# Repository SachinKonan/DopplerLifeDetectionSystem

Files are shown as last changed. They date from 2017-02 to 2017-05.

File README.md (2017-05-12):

# Doppler Radar Based Life Detection System

This project aimed at designing a low-cost Doppler radar system capable of detectin earthquake victims buried under rubble. The original system started with a cheap HB-100 system (located in ScienceFair2016), but after a summer's worth of research a from-scratch system was redesigned, requiring electrical and software innovation. The radar features a front-end clutter cancellation system which enables it to ignore the strong frontal reflections, allowing it to have hypersensitivity to signals through the rubble. Current work lies with redesigning the system on a printed circuit board for mobile deployment. 
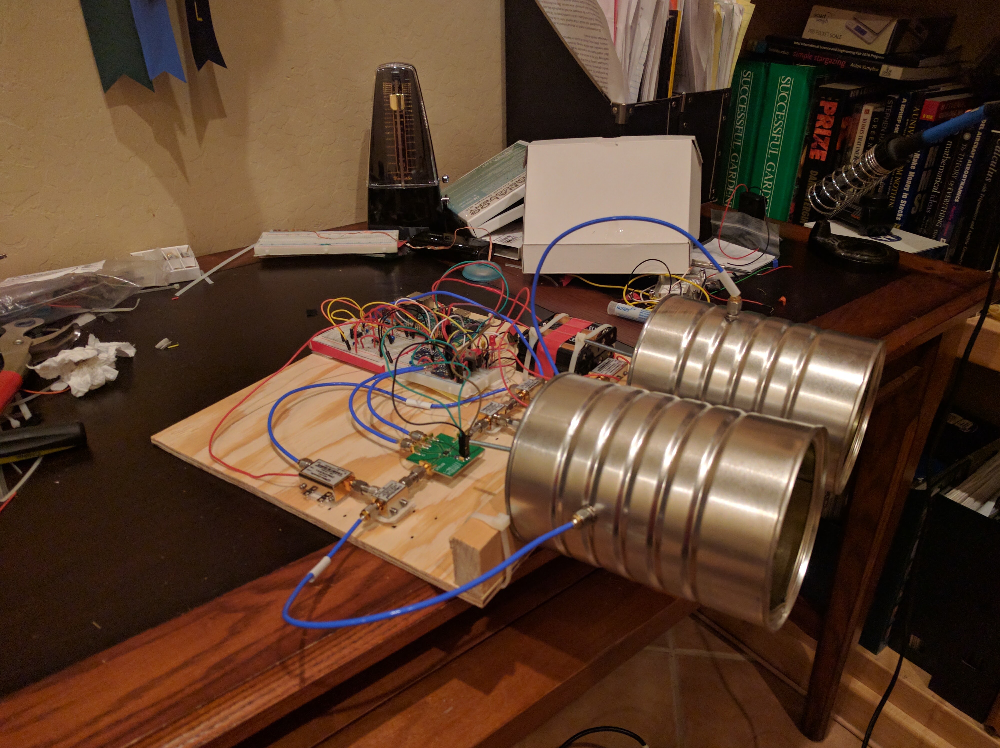
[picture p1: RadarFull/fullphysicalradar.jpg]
Doppler


## Research Paper
The full, Latex Paper can be found under the Research tab. 

## Hardware Build

The Schematic for the entire radar is found under the RadarFull tab. This includes the connections of the RF components, the filter/amplifier circuit, power supply, and list of materials.

### PCB

A PCB radar was designed on Upverter and the gerber files can be found in the PCBRadar folder. 

## Software

### Simple Oscillscope

Under main/SimpleOscilloscope a oscilloscope was designed as an intermediate step in the project, but may be a useful tool for anyone looking to debug circuits. The oscilloscope has a simple gui interface and the hookups of the connections can be found on the start page of the gui. 

### DAC And ADC Support

In order to speed up ADC and DAC control, threaded classes for the ADS-1115 and MCP-4725 were constructed -- main/ADC and main/DAC. These classes require the bare-bone libraries provided by adafruit: 

https://github.com/adafruit/Adafruit_Python_ADS1x15

https://github.com/adafruit/Adafruit_Python_MCP4725

These classes will run idly while simple getters and setters can be used to manipulate inputs/outputs. Additionally within the DAC folder sample classes for sin-wave, triangle-wave, square wave, and user set wave are provided. 

### Signal Processing

A FIR Filter and a Custom Signal Processing algorithm can be found in main/DSP. The Signal Processing algorithm is described in the paper. 

### Clutter Cancellatiion 

Found under main/Clutter-Cancellation. Currently in rats-nest state as the majority of testing occured in this folder. The results of the testing in the filter are found in the realmain.py file in main

### Radar Simulations

To demonstrate that DC offset corresponds to the amount of clutter in the radar system, a python simulation was constructed which can be found in main/Simulations. Once run
### Final

Once all pin connections are made correct according to the picture in main/radarfull.png, main/realmain.py can be run, which has three tabs.

1) Clutter Cancellation - Will run cancellation algorithm and minimize clutter in the receive antenna (approach described in paper). 
2) Data Collection and Processing - Will collect 2500 samples and output an FFT of the processed data. 
3) Simple Oscilloscope - Can be used for debugging within the system. 

# Author
Sachin Konan - Have been working on this work for 1.5 years +
James Aberle - Mentor for the project, aiding in rf clutter cancellation design.

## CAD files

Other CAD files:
CADFIles/Antenna.ipt
CADFIles/OldVersions/Antenna.0002.ipt
CADFIles/case.ipt
CADFIles/fullcase.iam

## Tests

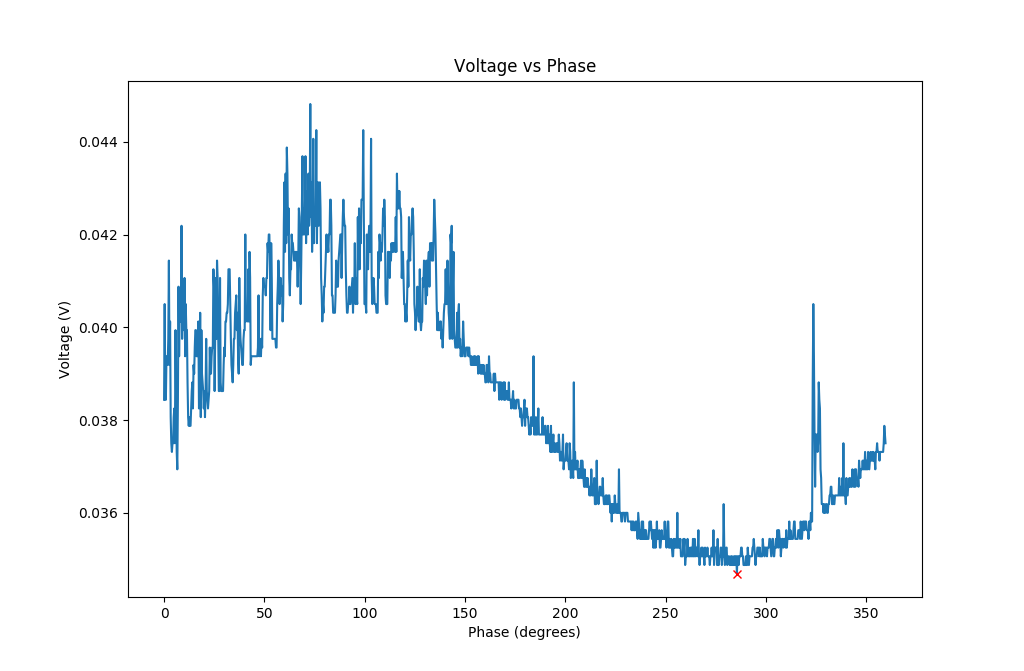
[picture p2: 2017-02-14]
main/CancellationCode/CalibrationGraphs/voltvsphase4.png

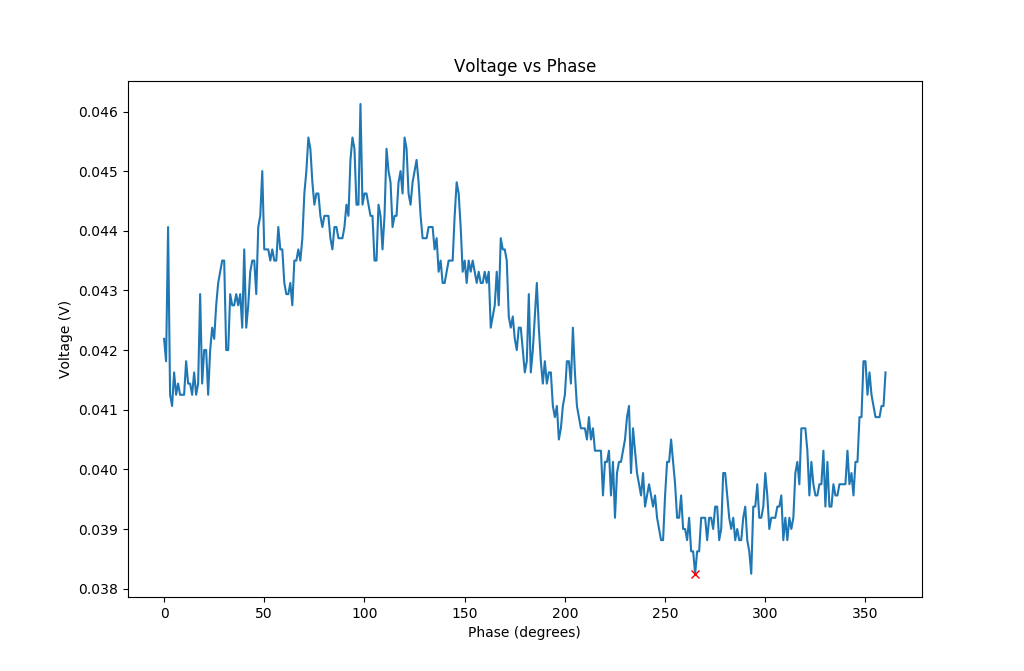
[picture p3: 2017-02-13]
main/CancellationCode/CalibrationGraphs/voltvsphase.png

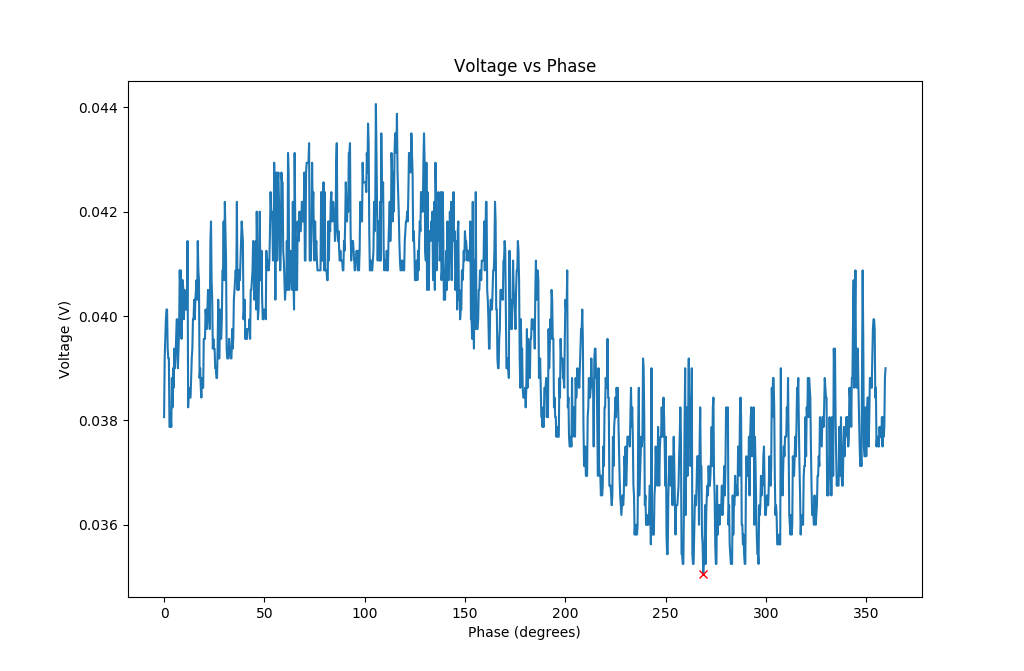
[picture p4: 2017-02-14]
main/CancellationCode/CalibrationGraphs/voltvsphase6.png

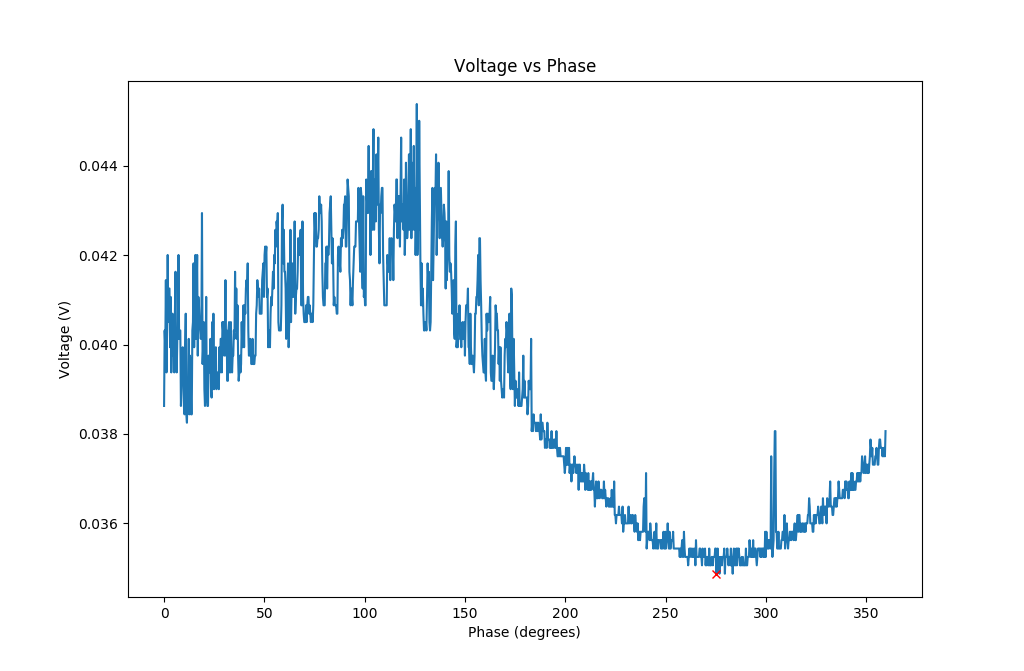
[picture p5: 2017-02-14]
main/CancellationCode/CalibrationGraphs/voltvsphase5.png

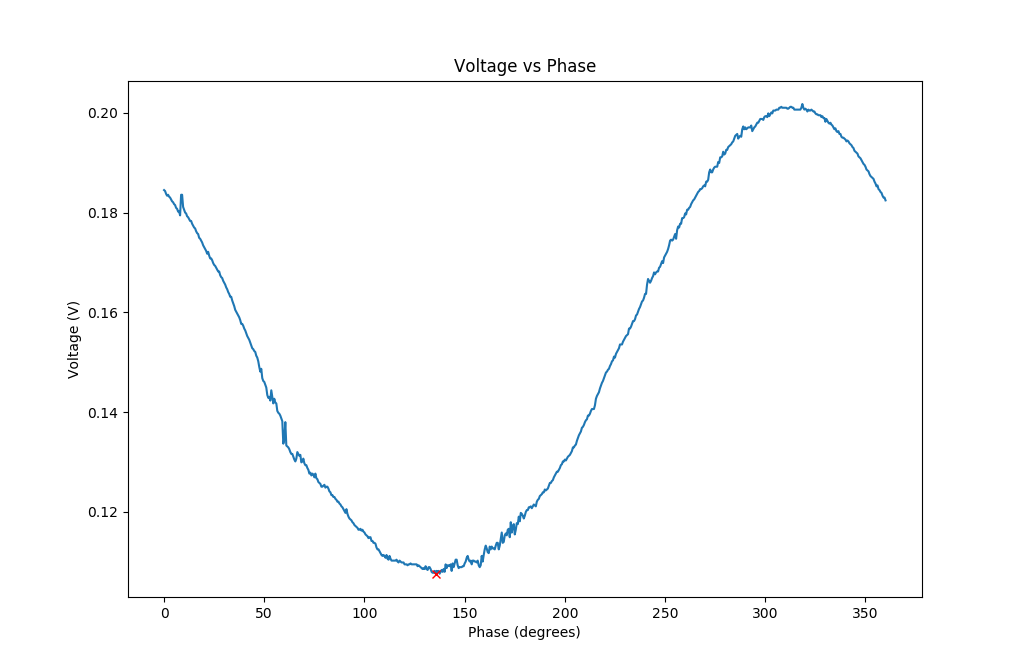
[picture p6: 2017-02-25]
main/CancellationCode/CalibrationGraphs/voltvsphasevalidation2.png

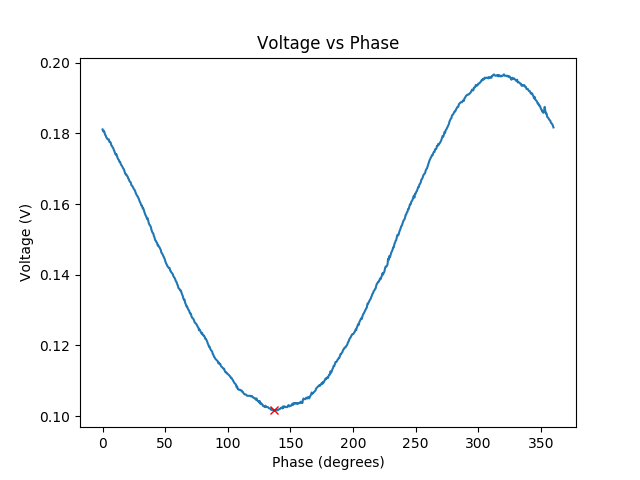
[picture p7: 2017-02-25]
main/CancellationCode/CalibrationGraphs/voltvsphasevalidatedwamp.png

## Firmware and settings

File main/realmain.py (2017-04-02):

import tkinter as tk
from tkinter import ttk
import matplotlib
import matplotlib.pylab as plt
from matplotlib.backends.backend_tkagg import FigureCanvasTkAgg, NavigationToolbar2TkAgg
from matplotlib.figure import Figure
from matplotlib import style
import time
from threading import Thread
import tkinter.simpledialog as simpledialog
import os
import numpy as np
import matplotlib.pyplot as plt
from scipy.fftpack import fft
from scipy.linalg import hankel
from scipy.signal import butter, lfilter, freqz
import Adafruit_ADS1x15
import Adafruit_MCP4725


def convertValtoVolt(x):
    return int((x / 3.3) * 4096.0)

class ADCThread:
    def __init__(self, address=0x48, gain=2 / 3, numthreads=1):
        self.i2caddress = address
        self.adc = Adafruit_ADS1x15.ADS1115(self.i2caddress)
        self.GAIN = gain
        self.numthreads = numthreads
        self.interrupt = False
        self.stopA1 = False
        self.stopA2 = False
        self.stopA3 = False
        self.adcval1 = 0
        self.adcval2 = 0
        self.adcval3 = 0
        self.adcval4 = 0
        self.samples = 0
        self.start_time = 0
        self.end_time = 0
        self.samplingrate = 0

    def start(self):
        Thread(target=self.channel, args=()).start()
        return self

        # self.start_time = time.time()
        # Thread(target = self.channel2,args = ()).start()

    def channel(self):
        i = 0
        i1 = 1
        while True:
            if (self.interrupt):
                return
            else:
                self.adcval1 = (self.adc.read_adc(0, gain=self.GAIN) / 32767.0) * 6.144
                self.adcval2 = (self.adc.read_adc(1, gain=self.GAIN) / 32767.0) * 6.144
                self.adcval3 = (self.adc.read_adc(2, gain=self.GAIN) / 32767.0) * 6.144
                self.adcval4 = (self.adc.read_adc(3, gain=self.GAIN) / 32767.0) * 6.144
                # self.end_time = time.time()
                # self.samples+=1
                time.sleep(0.01)

    def getADCVAL(self, var):
        if (var == 0):
            return self.adcval1
        elif (var == 1):
            return self.adcval2
        elif (var == 2):
            return self.adcval3
        elif (var == 3):
            return self.adcval4
        else:
            pass
    def stop(self):
        self.interrupt = True


class dacThreadVAL:
    def __init__(self, address):
        self.i2caddress = address
        self.interrupt = False
        self.dac = Adafruit_MCP4725.MCP4725(self.i2caddress)
        self.val = 0

    def start(self):
        print('Starting DAC Thread')
        Thread(target=self.valueset, args=()).start()
        return self

    def valueset(self):
        while True:
            if (self.interrupt):
                return
            else:
                if (self.val >= 0 and self.val <= 4096):
                    self.dac.set_voltage(self.val, True)

    def updateVal(self, val):
        self.val = val

    def stop(self):
        self.interrupt = True


style.use("ggplot")
matplotlib.use("TkAgg")
large_font = ("Verdana", 12)
small_font = ("Verdana", 8)

phasedac = dacThreadVAL(0x63).start()
ampdac = dacThreadVAL(0x62).start()
adc = ADCThread().start()
isOn = True
class MainGui(tk.Tk):
    def __init__(self, *args, **kwargs):
        tk.Tk.__init__(self, *args, **kwargs)
        container = tk.Frame(self)

        container.pack(side="top", fill="both", expand=True)
        container.grid_rowconfigure(0, weight=1)
        container.grid_columnconfigure(0, weight=1)
        self.frames = {}

        for F in (StartPage, PageOne, PageTwo, PageThree):
            frame = F(container, self)
            self.frames[F] = frame
            frame.grid(row=0, column=0, sticky="nsew")
        self.show_frame(StartPage)

    def show_frame(self, cont):
        frame = self.frames[cont]
        frame.tkraise()


class StartPage(tk.Frame):
    def __init__(self, parent, controller):
        tk.Frame.__init__(self, parent)
        label = tk.Label(self, text="Start Page", font=large_font)
        label.pack(pady=10, padx=10)
        button1 = ttk.Button(self, text="Calibration", command=lambda: controller.show_frame(PageOne))
        button1.pack()
        button2 = ttk.Button(self, text="Visit Data Acquisition", command=lambda: controller.show_frame(PageTwo))
        button2.pack()
        button3 = ttk.Button(self, text="Visit Oscilloscope", command=lambda: controller.show_frame(PageThree))
        button3.pack()


class PageOne(tk.Frame):
    def __init__(self, parent, controller):
        tk.Frame.__init__(self, parent)
        label = tk.Label(self, text="Calibration", font=large_font)
        label.pack(pady=10, padx=10)

        self.statuslabel = tk.Label(self, text="Not Calibrating", font=small_font, fg='red')
        self.statuslabel.pack(side=tk.BOTTOM)

        button = ttk.Button(self, text="Back to Home", command=lambda: controller.show_frame(StartPage))
        button.pack()

        button3 = ttk.Button(self, text="Calibration", command=self.calibrate)
        button3.pack()

        f = Figure(figsize=(6, 4), dpi=100)

        self.ax = f.add_subplot(2, 1, 1)
        self.ax2 = f.add_subplot(2, 1, 2)
        self.ax.text(.5, .9, 'Voltage vs Phase', horizontalalignment='center', transform=self.ax.transAxes, size=13,
                     color='r')
        self.ax2.text(.5, .9, 'Voltage vs Amp', horizontalalignment='center', transform=self.ax2.transAxes, size=13,
                      color='r')
        self.ax.grid(True)
        self.ax2.grid(True)

        self.canvas = FigureCanvasTkAgg(f, master=self)
        self.canvas.show()
        self.canvas.get_tk_widget().pack(side=tk.BOTTOM, fill=tk.BOTH, expand=True)

    def calibrate(self):
        gain = -10
        MAX_GAIN = -10
        keyvals = [10, 10]
        xvals = []
        yvals = []
        time.sleep(1)
        x = 0
        self.statuslabel['text'] = "Starting Phase"
        while (x <= 360):
            a = gain / 20
            b = MAX_GAIN / 20
            G = 10 ** a
            Gmax = 10 ** b
            vi = 1.5 + 1.0 * (G / Gmax) * np.cos(x * np.pi / 180)
            vq = 1.5 + 1.0 * (G / Gmax) * np.sin(x * np.pi / 180)
            phasedac.updateVal(convertValtoVolt(vi))
            ampdac.updateVal(convertValtoVolt(vq))
            time.sleep(0.08)
            val = adc.getADCVAL(0)
            # val = np.random.rand() * 2 - 1
            if (abs(val) < abs(keyvals[1])):
                keyvals[0] = x
                keyvals[1] = val
            xvals.append(x)
            yvals.append(val)
            x += 0.5
        # print('Min Phase: %s' % (keyvals[0]))
        # print('Min Voltage: %s' %(keyvals[1]))
        self.statuslabel['text'] = "Finished Phase, Starting AMP"
        self.ax.plot(xvals, yvals)
        self.ax.plot(keyvals[0], keyvals[1], marker='x', color='r')
        self.canvas.show()
        phase = keyvals[0]
        keygainvals = [[0, 0, 0], 10]

        xvals2 = []
        yvals2 = []
        while gain >= -40:
            a = gain / 20
            b = MAX_GAIN / 20
            G = 10 ** a
            Gmax = 10 ** b
            vi = 1.5 + 1.0 * (G / Gmax) * np.cos(phase * np.pi / 180)
            vq = 1.5 + 1.0 * (G / Gmax) * np.sin(phase * np.pi / 180)
            biti = convertValtoVolt(vi)
            bitq = convertValtoVolt(vq)
            phasedac.updateVal(biti)
            ampdac.updateVal(bitq)
            time.sleep(0.1)
            val = adc.getADCVAL(0)
            if (abs(val) < abs(keygainvals[1])):
                keygainvals[0][0] = biti
                keygainvals[0][1] = bitq
                keygainvals[0][2] = gain
                keygainvals[1] = val
            xvals2.append(gain)
            yvals2.append(val)

            gain -= 0.2
        self.statuslabel['text'] = "Finished AMP"
        self.ax2.plot(xvals2, yvals2)
        self.ax2.plot(keygainvals[0][2], keygainvals[1], marker='x', color='r')

        biti = keygainvals[0][0]
        bitq = keygainvals[0][1]

        phasedac.updateVal(biti)
        ampdac.updateVal(bitq)
        self.canvas.show()

class PageTwo(tk.Frame):
    def __init__(self, parent, controller):
        tk.Frame.__init__(self, parent)
        label = tk.Label(self, text="Data Acquisition", font=large_font)
        label.pack(pady=10, padx=10)

        button1 = ttk.Button(self, text="Back to Home", command=lambda: controller.show_frame(StartPage))
        button1.pack()

        self.statuslabel = tk.Label(self, text="Status", font=large_font)
        self.statuslabel.pack(pady=30, padx=30)

        button3 = ttk.Button(self, text="Data Acqusition Button for 2500 Samp", command=self.showBox)
        button3.pack()

        f = Figure(figsize=(6, 4), dpi=100)

        self.ax = f.add_subplot(1, 1, 1)
        self.ax.set_title("FFT of Selected Data")
        self.ax.set_xlabel("Frequency")
        self.ax.set_ylabel("Power (dB)")
        self.ax.grid(True)
        self.canvas = FigureCanvasTkAgg(f, master=self)
        self.canvas.show()
        self.canvas.get_tk_widget().pack(side=tk.BOTTOM, fill=tk.BOTH, expand=True)

    def showBox(self):
        string = simpledialog.askstring("Hello", "Prompt")

        if (string != None):
            self.statuslabel['text'] = "Starting Data Acquisistion"
            data, Fs = self.arraySampler()

            self.statuslabel['text'] = "Saving to: " + string
            path = 'C:\\Users\\Sachin Konan\\Documents\\ScienceFair2017\\main\\gui\\datasets'
            np.save(os.path.join(path, string), data)
            self.statuslabel['text'] = "Finished Saving"

            analysis = Radar(radar=data, samplingRate=Fs)
            output = analysis.main()
            mess = ''
            if (output['loc'] > 0.05 and output['loc'] < 3.3):
                mess = 'Possible Person'
            else:
                mess = 'None'
            self.ax.plot(output['fft'][0], output['fft'][1])
            self.ax.plot(output['loc'], output['peak'], marker='x', color='r')
            self.ax.text(output['fft'][0][len(output['fft'][0]) - 1] - 3, output['peak'] - 1, mess)
            self.canvas.show()

        else:
            pass

    def arraySampler(self):
        data = []
        start = time.time()
        for i in range(0, 2500):
            # data.append(adc.getADCVAL(0))
            data.append([np.random.rand() * 2 - 1, time.time()])
        end = time.time()
        Fs = (end - start) / 2500
        return data, Fs


class PageThree(tk.Frame):
    def __init__(self, parent, controller):
        tk.Frame.__init__(self, parent)

        self.controller = controller
        label = tk.Label(self, text="Oscilloscope", font=large_font)
        label.pack(pady=10, padx=10)

        button1 = ttk.Button(self, text="Back to Home", command=lambda: self.pageChanger())
        button1.pack()

        self.channel = 0
        self.label5 = tk.Label(self, text="Current Channel: " + str(self.channel), font=small_font)
        self.label5.pack(side=tk.BOTTOM)

        self.phase = tk.Scale(self, label="DAC1 :", from_=0, to=4096, sliderlength=20, length=400, orient=tk.HORIZONTAL)
        self.amplitude = tk.Scale(self, label="DAC2 :", from_=0, to=4096, sliderlength=20, length=400,orient=tk.HORIZONTAL)
        self.phase.pack(side=tk.TOP, padx=2, pady=5)
        self.amplitude.pack(side=tk.TOP, padx=2, pady=5)

        frame = tk.Frame(self)
        frame.pack(side=tk.RIGHT, fill=tk.BOTH)

        chan1 = ttk.Button(frame, text="Channel 0", command=lambda: self.add(0))
        chan1.pack(pady=35, padx=20)
        chan2 = ttk.Button(frame, text="Channel 1", command=lambda: self.add(1))
        chan2.pack(pady=35, padx=20)
        chan3 = ttk.Button(frame, text="Channel 2", command=lambda: self.add(2))
        chan3.pack(pady=35, padx=20)
        chan4 = ttk.Button(frame, text="Channel 3", command=lambda: self.add(3))
        chan4.pack(pady=35, padx=20)

        f = Figure(figsize=(5, 4), dpi=100)
        self.ax = f.add_subplot(111)
        self.ax.grid(True)

        xAchse = plt.arange(0, 100, 1)
        yAchse = plt.array([0] * 100)

        self.ax.grid(True)
        self.ax.set_title("Realtime Waveform Plot")
        self.ax.set_xlabel("Time")
        self.ax.set_ylabel("Amplitude")
        self.ax.axis([0, 100, -5, 5])
        self.line1 = self.ax.plot(xAchse, yAchse, '-')

        self.canvas = FigureCanvasTkAgg(f, master=self)
        self.canvas.get_tk_widget().pack(side=tk.LEFT, fill=tk.BOTH, expand=True)

        self.values = [0 for x in range(100)]

        # self.after(ms=100, func=self.SinwaveformGenerator)
        # self.after(ms=100, func=self.RealtimePlotter)

        self.thread = Thread(target=self.SinwaveformGenerator, args=())
        self.thread.start()

        self.thread1 = Thread(target=self.RealtimePlotter, args=())
        self.thread1.start()

    def pageChanger(self):
        self.controller.show_frame(StartPage)
        self.thread.join()
        self.thread1.join()

    def add(self, var):
        self.channel = var
        self.label5["text"] = "Current Channel is " + str(self.channel)

    def controlDACPhase(self):
        # print(self.phase.get())

        valstring = str(self.phase.get())

        try:
            val = int(valstring)
            # print(val)
            phasedac.updateVal(val)
        except ValueError:
            print("cant convert")
        self.update()

    def controlDACAmp(self):

        valstring = str(self.amplitude.get())

        try:
            val = int(valstring)
            # print(val)
            ampdac.updateVal(val)
        except ValueError:
            print("can't convert")
        self.update()

    def SinwaveformGenerator(self):

        # add adc stuff here
        # self.values.append(adc.getADCVAL(self.channel))
        self.controlDACPhase()
        self.controlDACAmp()
        # self.values.append(np.random.rand()*2 -1)
        self.values.append(adc.getADCVAL(self.channel))
        self.after(ms=25, func=self.SinwaveformGenerator)
        # time.sleep(0.025)
        # self.SinwaveformGenerator()

    def RealtimePlotter(self):
        CurrentXAxis = plt.arange(len(self.values) - 100, len(self.values), 1)
        self.line1[0].set_data(CurrentXAxis, plt.array(self.values[-100:]))
        self.ax.axis([CurrentXAxis.min(), CurrentXAxis.max(), 0, 5])
        self.canvas.draw()
        self.after(ms=25, func=self.RealtimePlotter)

    def converttoVolt(x):
        return (x / 4096) * 3.3


class Radar(object):
    def __init__(self, radar, samplingRate):
        self.radar = [radar[i][0] for i in range(0, len(radar))]
        self.time = [radar[i][1] for i in range(0, len(radar))]
        self.samplingRate = samplingRate
        self.p = 5
        self.nfft = 512
        self.list = []
        self.cutoff = 2
        self.radarobj = None
        self.order = 6

    def getVariables(self):
        return self.samplingRate, self.radar, self.time

    def main(self):
        radar, time = self.slidingwindow()
        fft = self.fft(radar)
        peakY = np.max(fft[1])  # Find max peak
        locY = fft[0][np.argmax(fft[1])]  # Find its location
        return {
            'fft': fft,
            'peak': peakY,
            'loc': locY
        }

    def slidingwindow(self):

        if (len(self.radar) == 2500):
            overlap = 0.4

            nw = 250
            ns = int(nw * (1.0 - overlap))
            n0 = 0
            n1 = n0 + nw
            N = len(self.radar)

            counter = 0
            counter1 = 1

            SNR = 0
            bestwin = 0
            besttime = 0
            while True:
                data = self.radar[n0:n1]
                time = self.time[n0:n1]
                array = Radar.HanningFunction(data)
                filtered_data = Radar.butter_lowpass_filter(array, self.cutoff, self.samplingRate, order=self.order)
                corrMtrx = self.getcorrMtrx(x=filtered_data, m=35)
                frequency, psd, eigenvals = self.musicAlg(corrMtrx)
                currSNR = sum(eigenvals[0:self.p]) / sum(eigenvals[self.p: len(eigenvals)])
                if (currSNR > SNR):
                    SNR = currSNR
                    bestwin = filtered_data
                    besttime = time
                # r = counter // n
                # c = counter % n
                # ax[r][c].plot(eigenvals)
                # ax[r][c + 1].plot(xf, yf)
                n0 += ns
                n1 += ns
                counter += 2
                counter1 += 1
                if n1 > N:
                    break

            return bestwin, besttime
        else:
            print("Error your data vector is not the proper length")

    def diffCalc(self, list1):
        list2 = []
        for i in range(1, len(list1)):
            list2.append(list1[i] - list1[i - 1])
        return list2

    def fft(self, array):
        yf = fft(array, n=self.nfft)
        xf = np.linspace(0.0, self.samplingRate / 2, self.nfft / 2)
        return xf, abs(yf[0:self.nfft / 2])

    def HanningFunction(radarData):
        return radarData * np.hanning(len(radarData))

    def getcorrMtrx(self, x, m):
        x = np.array(x)
        m = m
        N = len(x)
        xlen = m + 1
        rowVector = x[N - xlen: N]
        columnVector = x[0: N - m]
        hanMatrix = hankel(c=np.array(columnVector).T, r=rowVector)
        X_unscaled = np.fliplr(hanMatrix)
        X = X_unscaled / np.sqrt(N - m)
        Xnew = np.conj(np.fliplr(X))
        corrMatrix = np.vstack((X, Xnew)) / np.sqrt(2)
        return corrMatrix

    def musicAlg(self, corrMtrx):
        u, s, v = np.linalg.svd(corrMtrx)

        self.nfft = 512

        frequencyVector = np.linspace(0, 1, self.nfft // 2)
        frequencyVector *= self.samplingRate / 2

        sum = 0
        for i in range(self.p, len(v)):
            y = fft(v[i], n=self.nfft)
            sum += abs(y) ** 2 / s[i]

        sum = 1 / sum

        sum = sum[0:self.nfft // 2]

        return frequencyVector, sum, s

    def graphFilterResults(self):
        order = 6
        cutoff = 2

        b, a = Radar.butter_lowpass(cutoff, self.samplingRate, order)

        w, h = freqz(b, a, worN=8000)
        plt.subplot(2, 1, 1)
        plt.plot(0.5 * self.samplingRate * w / np.pi, np.abs(h), 'b')
        plt.plot(cutoff, 0.5 * np.sqrt(2), 'ko')
        plt.axvline(cutoff, color='k')
        plt.xlim(0, 0.5 * self.samplingRate)
        plt.title("Lowpass Filter Frequency Response")
        plt.xlabel('Frequency [Hz]')
        plt.grid()

        y = Radar.butter_lowpass_filter(self.radar, cutoff, self.samplingRate, order)

        plt.subplot(2, 1, 2)
        plt.plot(self.time, self.radar, 'b-', label='data')
        plt.plot(self.time, y, 'g-', linewidth=2, label='filtered data')
        plt.xlabel('Time [sec]')
        plt.grid()
        plt.legend()

        plt.subplots_adjust(hspace=0.35)
        plt.show()
        return y

    def butter_lowpass(cutoff, fs, order=5):
        nyq = 0.5 * fs
        normal_cutoff = cutoff / nyq
        b, a = butter(order, normal_cutoff, btype='low', analog=False)
        return b, a

    def butter_lowpass_filter(data, cutoff, fs, order=5):
        b, a = Radar.butter_lowpass(cutoff, fs, order=order)
        y = lfilter(b, a, data)
        return y

    def testSpectrum(self, data):
        corrMtrx = self.getcorrMtrx(data, 30)
        return self.musicAlg2(corrMtrx)

    def musicAlg2(self, corrMtrx):
        u, s, v = np.linalg.svd(corrMtrx)
        self.nfft = 512
        frequencyVector = np.linspace(0, 1, self.nfft // 2)
        frequencyVector *= self.samplingRate / 2
        sum = 0
        for i in range(self.p, len(v)):
            y = fft(v[i], n=self.nfft)
            sum += abs(y) ** 2 / s[i]

        sum = 1 / sum

        sum = sum[0:self.nfft // 2]

        return frequencyVector, sum, s


def on_closing():
    if tk.messagebox.askokcancel("Quit", "Do you want to quit?"):
        app.destroy()
    else:
        isOn = True


app = MainGui()
app.protocol("WM_DELETE_WINDOW", on_closing)
app.mainloop()

phasedac.stop()
ampdac.stop()
adc.stop()

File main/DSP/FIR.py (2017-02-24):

import numpy as np
from scipy import signal
import matplotlib.pyplot as plt


def plot_response(fs, w, h, title):
    plt.figure()
    plt.plot(0.5*fs*w/np.pi, 20*np.log10(np.abs(h)))
    plt.ylim(-40, 5)
    plt.xlim(0, 0.5*fs)
    plt.grid(True)
    plt.xlabel('Frequency (Hz)')
    plt.ylabel('Gain (dB)')
    plt.title(title)


# Low-pass filter design parameters
fs = 22050.0       # Sample rate, Hz
cutoff = 8000.0    # Desired cutoff frequency, Hz
trans_width = 250  # Width of transition from pass band to stop band, Hz
numtaps = 125      # Size of the FIR filter.

taps = signal.remez(numtaps, [0, cutoff, cutoff + trans_width, 0.5*fs],
                    [1, 0], Hz=fs)
w, h = signal.freqz(taps, [1], worN=2000)

plt.plot(w,h)
plt.grid()
plt.show()

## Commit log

2016-12-22 Added DAC and ADC Code
2017-01-19 added spice files
    [Antenna.0002.ipt, Antenna.ipt, case.ipt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]
2017-01-24 added new adc
2017-01-27 added threaded files
2017-01-30 added adc code
2017-02-13 finished calibration
2017-02-22 changed circuit
2017-03-24 added dac and adc threads
